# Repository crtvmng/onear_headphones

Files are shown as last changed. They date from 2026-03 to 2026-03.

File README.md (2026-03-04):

## 📖 Overview






This project is a fully custom-designed, portable high-resolution audio device combining a flagship **ESS Sabre DAC**, an ultra-low-noise power architecture, and a high-current amplification stage into a single compact PCB. It is built from the ground up to handle the unique electrical demands of planar magnetic headphone drivers — low impedance, high current, and wide bandwidth.

The design targets:

* 🎧 **Planar magnetic headphones** (HiFiMAN, Audeze, Fostex RP-series)
* 💻 **USB Audio Class 2.0** — driverless on macOS/Linux, ASIO on Windows
* 🔋 **Portable operation** — Li-Po battery with smart power-path management
* 📐 **DIY / open-source** — fully documented schematic & PCB in Altium Designer

--- 
## ⚡ Key Components 
### Core Processing & Communication 
| Block | Component | Role | 
|---|---|---|
| *MCU* | STM32F446 (ARM Cortex-M4 @ 180MHz) | USB Audio 2.0 host, I2S master, firmware | 
| *DAC* | ESS Sabre ES9039Q2M | 32-bit stereo, HyperStream® IV, −122 dB THD+N | 
| *Clock* | Si5351A | External master clock, eliminates MCU jitter | 
| *Amplifier* | TI OPA1622 (SoundPlus™) | 145 mA output current, drives planar magnetics |

---
### Power Architecture 
| Rail | Component | Spec |
|---|---|---|
| *Analog LDO* | LT3045 | Ultra-low noise (2 µV RMS), 76 dB PSRR | 
| *Power-path* | BQ24072 | USB ↔ Li-Po seamless switching | 
| *Soft-start LDO* | TLV75533 | PWR\_HOLD logic, battery protection | 
| *ESD Protection* | USBLC6-2 | USB port transient protection | 

--- 
## 🔬 Technical Highlights 
### Planar-Ready Amplification 
The **OPA1622** output stage is configured with a bipolar supply rail (±) to provide the full voltage swing and instantaneous current delivery needed by low-impedance planar membranes. Unlike dynamic drivers, planars require the amplifier to maintain grip across the entire frequency range without current clipping. 
### Precision Clocking 
The **Si5351A** external clock generator feeds a dedicated, jitter-cleaned MCLK directly to the ES9039Q2M, bypassing the STM32's internal PLL. This ensures bit-perfect audio synchronisation for high-resolution PCM (up to 384 kHz) and native DSD playback. 
### Analog Power Isolation 
The **LT3045** ULNLDO is dedicated exclusively to the DAC's AVCC and AVCC33 rails. Its extraordinary PSRR (>80 dB at 1 MHz) and ultra-low output noise floor (2 µV RMS) prevent any switching activity on the digital plane from coupling into the audio signal path. 
### PCB Layout Strategy 
- ✅ **Split ground planes** — Digital (DGND) and Analog (AGND) planes joined at a single star point via NetTie
- ✅ **Series termination resistors** on all I2S / MCLK / BCLK lines to suppress reflections and EMI
- ✅ **C0G/NP0 dielectrics** for all analog filter capacitors (no piezoelectric distortion) -
- ✅ **Low-ESR polymer/tantalum caps** for power supply decoupling -
- ✅ **Guard rings** around DAC analog outputs

--- 
## 📋 Specifications 
| Parameter | Value |
|---|---|
| **USB Interface** | USB Type-C, Audio Class 2.0 (Async) |
| **Max PCM Resolution** | 32-bit / 384 kHz | 
| **DSD Support** | DSD64 / DSD128 (DoP) | 
| **THD+N (DAC)** | −122 dB (typical) |
| **Output Current (Amp)** | 145 mA (peak) |
| **Output Impedance** | < 1 Ω |
| **Headphone Outputs** | 4.4 mm Balanced + 3.5 mm Single-ended | 
| **Power Source** | USB 5V / Li-Po 3.7V (via BQ24072) |
| **SNR** | > 120 dB |

---

## 🚀 Getting Started

### Prerequisites

- **Altium Designer** 22+ (for hardware files)
- **STM32CubeIDE** (for firmware)
- **ST-Link V2** or compatible SWD programmer

### PCB Fabrication Notes

> ⚠️ This board requires a **4-layer stackup** for proper impedance control and plane separation.

| Layer | Function |
|---|---|
| **L1 (Top)** | Signal (USB, I2S, analog out) |
| **L2** | Solid GND plane |
| **L3** | Power plane (split DGND / AGND) |
| **L4 (Bottom)** | Signal (power routing, decoupling) |

Recommended: **JLCPCB / PCBWay** with ENIG finish, 1 oz copper, controlled impedance (90 Ω differential for USB lines).

---

## 🧩 Compatible Headphones

| Model | Impedance | Sensitivity | Notes |
|---|---|---|---|
| HiFiMAN HE400se | 25 Ω | 91 dB/mW | ✅ Excellent match |
| Audeze LCD-2 | 70 Ω | 101 dB/mW | ✅ Excellent match |
| Fostex T50RP Mk3 | 50 Ω | 92 dB/mW | ✅ Good match |
| Audeze LCD-4 | 200 Ω | 97 dB/mW | ✅ Works on balanced out |

---

## 📌 Status & Roadmap

- [x] Schematic design — Rev A
- [x] Component selection & BOM
- [ ] PCB layout — in progress
- [ ] Rev A fabrication & bring-up
- [ ] Firmware: USB Audio 2.0 enumeration
- [ ] Firmware: ES9039Q2M register map & init
- [ ] Firmware: Si5351A clock configuration
- [ ] Listening tests & measurements (REW / APx)
- [ ] Rev B (post-bringup corrections)

---

## License
This project is licensed under the **CERN Open Hardware License v2 - Weakly Permissive (CERN-OHL-W-2.0)**. 
For more details, see the [LICENSE](LICENSE) file.

---

<div align="center">
*Built with obsessive attention to analog signal integrity.*
<br/>

</div>

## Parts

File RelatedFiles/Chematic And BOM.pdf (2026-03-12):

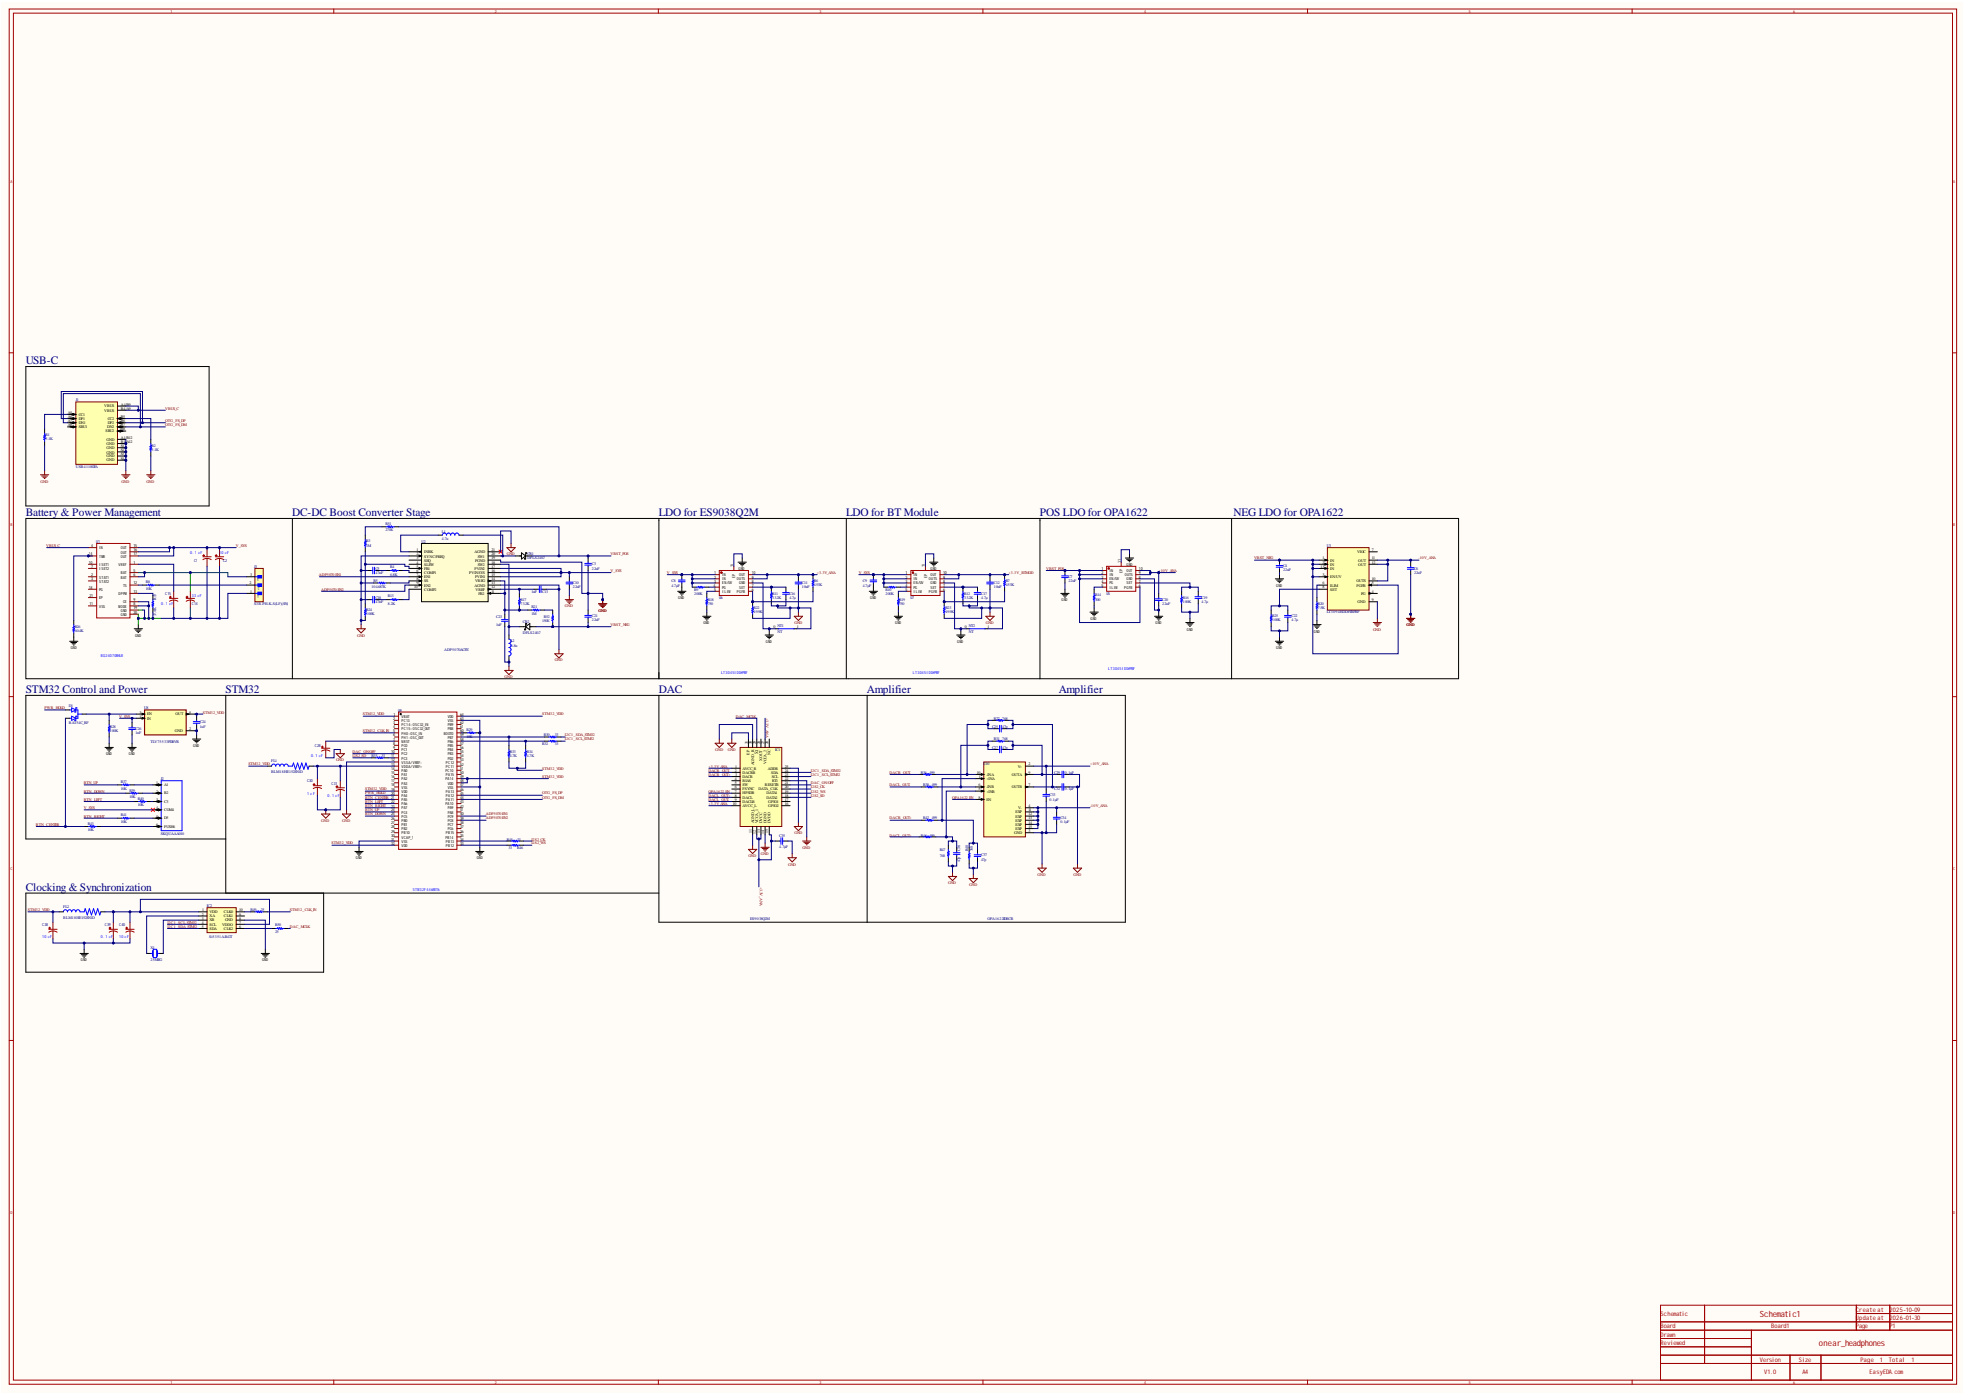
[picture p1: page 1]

VB CC 1 VB US DP DN 1 1 CC2 DP2 S BU1 S DN2 BU2 GND GND GND GND GND | 4 /A9

X1 | I 2 C 1 _ S C L_STM3 I 2 C 1 _ SDA_STM3 | 2 2 S S CL DA VDD C L K2 O

Line# | Name | Description | Designator | Quantity | Manufacturer 1 | Manufacturer Part Number 1 | Manufacturer Lifecycle1 | Supplier 1 | Supplier Part Number 1 | Supplier Unit Price1 | Supplier Subtotal 1
| 0.1μF | | C1 | | 1 Murata | GRM155R71H104KE14D | VolumeProduction | Mouser | 81-GRM155R71H104KE4D | 0,1 | 0,1
| 10μF | | C2 | | 1 CCTC | TCC0805X7R106K160FT | Manual Solution | LCSC | C380347 | 0,0215 | 0,0215
| Capacitor | Capacitor | C3, C4, C6, C7, C10, C20, C21 | | 7 Murata | GRM32ER71H106KA12L | VolumeProduction | Arrow Electronics | GRM32ER71H106KA12L | 0,3643 | 364,3
| Capacitor | Capacitor | C5, C18 | | 2 Murata | GRM155R71H473KE14D | VolumeProduction | Farnell | 3582817 | 0,01597 | 0,15966
| Capacitor | Capacitor | C8, C9 | | 2 SamsungElectro-Mechanics | CL10A475KA8NQNC | VolumeProduction | Mouser | 187-CL10A475KA8NQNC | 0,21 | 0,42
| Capacitor | Capacitor | C11, C12 | | 2 Murata | GRM32ER71H106KA12L | VolumeProduction | Arrow Electronics | GRM32ER71H106KA12L | 0,3643 | 364,3
| Capacitor | Capacitor | C13, C23, C24, C26 | | 4 SamsungElectro-Mechanics | CL10B105KA8NNNC | VolumeProduction | Farnell | 3013415 | 0,01825 | 0,18246
| 33μF | | C14 | | 1 KEMET | T495D336K016ATE225 | VolumeProduction | Arrow Electronics | T495D336K016ATE225 | 0,1318 | 0,1318
| 0.1μF | | C15, C28, C31, C39 | | 4 Murata | GRM155R71H104KE14D | VolumeProduction | Mouser | 81-GRM155R71H104KE4D | 0,016 | 0,16
| Capacitor | Capacitor | C16, C17, C19, C22 | | 4 SamsungElectro-Mechanics | CL10B475KQ8NQNC | VolumeProduction | Mouser | 187-CL10B475KQ8NQNC | 0,053 | 0,53
| Capacitor | Capacitor | C25, C27, C36, C37 | | 4 Murata | GCM1555C1H470JA16D | VolumeProduction | Future Electronics | 5120075 | 0,0028 | 28
| Capacitor | Capacitor | C29, C32, C33, C34 | | 4 Murata | GRM155R71H104KE14D | VolumeProduction | Mouser | 81-GRM155R71H104KE4D | 0,016 | 0,16
| 1μF | | C30 | | 1 KEMET | C0402C105K4PACTU | VolumeProduction | Mouser | 80-C0402C105K4P | 0,17 | 0,17
| Capacitor | Capacitor | C35 | | 1 SamsungElectro-Mechanics | CL10B475KQ8NQNC | VolumeProduction | Avnet | 82AC9361 | 0,134 | 0,134
| 10μF | | C38, C40 | | 2 SamsungElectro-Mechanics | CL21B106KOQNNNE | VolumeProduction | Mouser | 187-CL21B106KOQNNNE | 0,12 | 0,24
| DFLS240-7 | Description | CR1, CR2 | | 2 Diodes Inc. | DFLS240-7 | VolumeProduction | Mouser | 621-DFLS240-7 | 0,77 | 1,54
| BAT54C_RF | SOT-23, 30V, 0.2A, Schottky Diode | D1 | | 1 Taiwan Semiconductor | BAT54CRFG | VolumeProduction | Mouser | 821-BAT54CRFG | 0,13 | 0,13
| BLM18HE152SN1D | 1.5kOhms@ 100MHz1 Signal Line FerriteBead 0603(1608 Metric) 500mA 500mOhm | FL1, FL2 | | 2 Murata | BLM18HE152SN1D | VolumeProduction | Mouser | 81-BLM18HE152SN1D | 0,18 | 0,36
| ES9038Q2M | Integrated Circuit | IC1 | | 1 ESS | ES9038Q2M | Unknown | Mouser | 460-ES9038Q2M | 19,2 | 19,2
| Si5351A-B-GT | Integrated Circuit | IC2 | | 1 Skyworks Solutions | SI5351A-B-GT | VolumeProduction | Mouser | 634-SI5351A-B-GT | 2,11 | 2,11
| USB4110GFA | USB-C(USB TYPE-C) USB 2.0Receptacle Connector 24 (16+8Dummy) Position Surface Mount, Right Angle | J1 | | 1 Global Connector Technology | USB4110-GF-A | VolumeProduction | Mouser | 640-USB4110-GF-A | 1,4 | 1,4
| SKQUAAA010 | | J2 | | 1 MARSHALL_DONO R | 1 | Manual Solution | ME | 1 | 1 | | 1
| S3B-PH-K-S(LF)(SN) | CONN HEADER R/A3POS2MM | J3 | | 1 JST | S3B-PH-K-S(LF)(SN) | VolumeProduction | Mouser | 306-S3BPHKSLFSN | 0,12 | 0,12
| Inductor | Inductor | L1 | | 1 Wurth Elektronik | 74438357047 | Unknown | Mouser | 710-74438357047 | 1,68 | 1,68
| Inductor | Inductor | L2 | | 1 Wurth Elektronik | 74438357068 | Unknown | Mouser | 710-74438357068 | 1,68 | 1,68
| Resistor | Resistor | R1, R2 | | 2 Yageo Group | RC0402FR-075K1L | VolumeProduction | Mouser | 603-RC0402FR-075K1L | 0,005 | 0,05
| Resistor | Resistor | R3, R21 | | 2 Panasonic | ERA8AEB105V | VolumeProduction | Mouser | 667-ERA-8AEB105V | 0,24 | 0,48
| Resistor | Resistor | R4 | | 1 Yageo Group | RT0402BRD076K8L | VolumeProduction | Mouser | 603-RT0402BRD076K8L | 0,29 | 0,29
| Resistor | Resistor | R5 | | 1 Yageo Group | RT0402BRD07105KL | VolumeProduction | Mouser | 603-RT0402BRD07105KL | 0,15 | 0,15
| Resistor | Resistor | R6, R7 | | 2 CHANGLONG | CL0402FN470KP | Manual Solution | LSCS | C46635183 | 0,0007 | 0,0014
| Resistor | Resistor | R8, R29, R37, R39, R40, R41, R43 | | 7 Yageo Group | RC0402FR-0710KL | VolumeProduction | Mouser | 603-RC0402FR-0710KL | 0,007 | 0,07
| Resistor | Resistor | R9, R10 | | 2 Yageo Group | RC0402FR-07200KL | VolumeProduction | Farnell | 1458761 | 0,00416 | 0,04159
| Resistor | Resistor | R11, R12 | | 2 Panasonic | ERA-2AEB3322X | VolumeProduction | Mouser | 667-ERA-2AEB3322X | 0,1 | 0,2
| Resistor | Resistor | R13 | | 1 Yageo Group | RT0402BRD078K2L | VolumeProduction | Mouser | 603-RT0402BRD078K2L | 0,1 | 0,1
| Resistor | Resistor | R14 | | 1 Panasonic | ERA-2AEB301X | VolumeProduction | Mouser | 667-ERA-2AEB301X | 0,1 | 0,1
| Resistor | Resistor | R15 | | 1 Panasonic | ERA-2AEB3742X | VolumeProduction | Arrow Electronics | ERA-2AEB3742X | 0,0084 | 0,0084
| Resistor | Resistor | R16, R24, R25, R28 | | 4 Panasonic | ERA-2AEB104X | VolumeProduction | Mouser | 667-ERA-2AEB104X | 0,1 | 0,4
| Resistor | Resistor | R17 | | 1 Panasonic | ERA-2AEB7322X | VolumeProduction | Mouser | 667-ERA-2AEB7322X | 0,1 | 0,1
| Resistor | Resistor | R18, R19 | | 2 Panasonic | ERA-2AEB751X | VolumeProduction | Arrow Electronics | ERA-2AEB751X | 0,019 | 0,038
| Resistor | Resistor | R20 | | 1 Yageo Group | RT0402BRD077K5L | VolumeProduction | Arrow Electronics | RT0402BRD077K5L | 0,0252 | 0,0252
| Resistor | Resistor | R22, R23 | | 2 Panasonic | ERA-2AEB4992X | VolumeProduction | Farnell | 2563607 | 0,08318 | 0,83182
| Res_0603 | Resistor | R26 | | 1 Yageo Group | RC0402FR-0760K4L | VolumeProduction | Farnell | 3495651 | 0,00926 | 0,09257
| Resistor | Resistor | R27, R31, R47, R48 | | 4 Panasonic | ERA2AEB7680X | VolumeProduction | Mouser | 667-ERA-2AEB7680X | 0,1 | 0,4
| Resistor | Resistor | R30, R32, R35, R45, R46 | | 5 Yageo Group | RT0402BRD0733RL | VolumeProduction | Mouser | 603-RT0402BRD0733RL | 0,047 | 0,47
| Resistor | Resistor | R33, R34 | | 2 Yageo Group | RC0402FR-074K7L | VolumeProduction | Mouser | 603-RC0402FR-074K7L | 0,004 | 0,04
| Resistor | Resistor | R36, R38, R42, R44 | | 4 Panasonic | ERA-2AEB4990X | VolumeProduction | Mouser | 667-ERA-2AEB4990X | 0,1 | 0,4
| Resistor | Resistor | R49, R50 | | 2 Yageo Group | RT0402BRD0724R9L | VolumeProduction | Mouser | 603-RT0402BRD0724R9L | 0,2 | 0,4
| Resistor | Resistor | R51 | | 1 KOA | RS73F2BTTD2703B | Manual Solution | LCSC | C4216782 | 0,0978 | 0,0978
| Resistor | Resistor | R52 | | 1 Panasonic | ERA-6AEB154V | VolumeProduction | Mouser | 667-ERA-6AEB154V | 0,1 | 0,1
| BQ24070RHLR | | U1 | | 1 Texas Instruments | BQ24070RHLR | VolumeProduction | Mouser | 595-BQ24070RHLR | 2,72 | 2,72
| ADP5070ACPZ | 1A/0.6A, DC-to-DC Switching Regulator with Independent Positiveand Negative Outputs | U2 | | 1 AnalogDevices | ADP5070ACPZ | VolumeProduction | Newark | ADP5070ACPZ | 6,1 | 6,1
| LT3094HDD#TRPBF | âˆ’20V, 500mA, Ultralow Noise, Ultrahigh PSRR Negative Linear Regulator | U3 | | 1 AnalogDevices | LT3094HDD#TRPBF | VolumeProduction | Mouser | 584-LT3094HDD#TRPBF | 11,12 | 11,12
| LT3045IDD#PBF | | U5, U6, U7 | | 3 AnalogDevices | LT3045IDD#TRPBF | VolumeProduction | Newark | LT3045IDD#TRPBF | 10,76 | 32,28
| TLV75533PDBVR | 500-mAHigh-PSRRLow-IQ-Tief-Dropout-Spannungsreg ler mitablem | U8 | | 1 Texas Instruments | TLV75533PDBVR | VolumeProduction | Mouser | 595-TLV75533PDBVR | 0,36 | 0,36
| STM32F446RET6 | | U9 | | 1 STMicroelectronic s | STM32F446RET6 | VolumeProduction | Arrow Electronics | STM32F446RET6 | 4,35 | 4,35
| OPA1622IDRCR | SoundPlusâ„¢ Audio Operational Amplifier with High Performance, Low THD+N and Bipolar Input | U10 | | 1 Texas Instruments | OPA1622IDRCR | VolumeProduction | Mouser | 595-OPA1622IDRCR | 6,62 | 6,62
| Crystal | Crystal | X1 | | 1 NDK | NX3225SA-25.000M-STD-CRS-2 | VolumeProduction | Mouser | 344-NX3225SA25MSTRS2 | 1,08 | 1,08

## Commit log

2026-03-04 Fixed some issues with LT3045
    Fixed issues with LT3045 and added another one for 3.3V for ES9038Q2M
    [1_P1.schdoc]
2026-03-08 Fix some DAC connections
    [1_P1.schdoc]
2026-03-09 Update Schematic
    Schematic blocks translation.
    Almost finished the OPA1622 peripheral circuitry.
    [1_P1.schdoc]
2026-03-09 finished the OPA1622 peripheral circuitry
    finished the OPA1622 peripheral circuitry
    [1_P1.schdoc]
2026-03-09 Minor changes for understanding circuit
    [1_P1.schdoc]
2026-03-10 Change Boost converter
    Changed boost converter from TPS61088 to ADP5070.
    The change is needed for getting Same negative and positive voltage for OPA1622
    [1_P1.schdoc]
2026-03-10 Deleted TPS61088 from schematic
    [1_P1.schdoc]
2026-03-10 Review LT3045 Config
    Review LT3045 Config for OPA1622. Changed few things
    [1_P1.schdoc]
2026-03-10 Added LDO for Negative 10V
    Added LDO LT3094 for Negative 10V from ADP5070
    [1_P1.schdoc]
2026-03-10 just checking
    [1_P1.schdoc, headphones.PrjPcb]
2026-03-11 Firs review of BOM
    Working on BOM and adding elements.
    Need to find few resistors and capacitors.
    Need no change 2 capacitors and chose new ones.
    [1_P1.schdoc]
2026-03-11 Added Related files
    Added datasheets, Schematic.pdf and BOM.pdf
2026-03-11 Just saving
    [headphones.PrjPcb]
2026-03-11 Update BOM and Chematic
    Changed 1.275МOhm resistors to two resistor connected in serial. It helped find resistor from manufacture.
    Did same to 1.150MOhm resistor
    [1_P1.schdoc]
2026-03-11 Added PDF
    [1_P1.schdoc]
2026-03-11 Finished BOM
    [1_P1.schdoc]
2026-03-12 Added most of the footprints
    [1_P1.schdoc, PCB1.pcbdoc, headphones.PrjPcb]
2026-03-12 Finished footprints and fixed nettie
    [1_P1.schdoc, PCB1.pcbdoc]
2026-03-12 Just Save
    [PCB1.pcbdoc]
2026-03-12 Update BOM and added Libraries
    Added a solution for the battery connector.
    Also added library files to use(some of them need Component Search Engine (SamacSys) with Altium Library Loader
    [headphones.PrjPcb]
2026-05-23 Some little arrangement
    [1_P1.schdoc, PCB1.pcbdoc]
